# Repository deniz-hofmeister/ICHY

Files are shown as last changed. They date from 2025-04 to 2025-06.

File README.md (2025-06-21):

# ICHY - 8-Element Microphone Phased Array

## Project Overview
ICHY is a 8-element microphone phased array designed for high-precision audio source localization and beamforming. This document outlines the key design considerations, components, and implementation approach.

## Key Design Elements

### Hardware
- **Microphones**: 8 MEMS microphones with matched frequency response
- **Geometry**: Square array of 4x4 microphones
- **Spacing**: λ/2 spacing to prevent spatial aliasing at target frequencies
- **ADC**: Simultaneous sampling across all channels

### Signal Processing
- **Beamforming Algorithm**: Delay-and-sum with optional adaptive algorithms
- **Calibration**: Inter-microphone calibration methodology
- **Filtering**: Band-pass filtering to focus on frequencies of interest
- **Direction Finding**: MUSIC or SRP-PHAT algorithm implementation

### Software
- **DSP Pipeline**: Real-time processing chain
- **Visualization**: Direction-of-arrival display
- **Interface**: Configuration and monitoring interface
- **Data Storage**: Recording capabilities for post-processing

### Performance Targets
- **Angular Resolution**: <5° at target frequency range
- **Frequency Range**: 1kHz - 8kHz optimal operation
- **Processing Latency**: <50ms for real-time applications

## Data Acquisition Architecture

### Minimal Hardware Configuration for Jetson Processing

#### Essential Hardware Components
- **Microphones**: 8 digital MEMS microphones (I2S/PDM output)
- **Clock Source**: Single master clock with distribution network to ensure phase alignment
- **Audio Codec/Interface**: Audio interface with multi-channel input capabilities
- **Physical Array Structure**: Precise physical positioning framework for microphones
- **Power Conditioning**: Clean power supply with proper isolation

#### Non-Replaceable Hardware Elements
1. **Microphone Transducers**: Physical conversion of sound to electrical signals cannot be done in software
2. **Clock Synchronization Hardware**: Physical timing alignment between microphones (~1μs precision)
3. **Physical Array Geometry**: Precise spatial positioning that affects beamforming accuracy
4. **Signal Conditioning**: Analog filters and buffers to maintain signal integrity
5. **ADC Hardware**: Conversion from analog to digital (integrated in digital MEMS mics)

### Jetson-Based Processing Approach
- **Direct Interfaces**: Utilize Jetson's I2S/SPI interfaces for direct microphone connection where possible
- **Audio Interface Options**:
  1. Direct connection of PDM microphones to Jetson's hardware interfaces
  2. Multi-channel audio codec with TDM output connected to Jetson
  3. USB audio interface with multi-channel capability

### Software-Replaceable Components
- **Digital Filtering**: All filtering can be performed in software on Jetson
- **Beamforming Algorithms**: Implemented entirely in CUDA on Jetson GPU
- **Signal Conditioning**: Digital gain, normalization in software
- **Channel Synchronization**: Fine synchronization adjustments in software
- **Calibration**: Software-based microphone calibration routines
- **Direction Finding**: All direction finding algorithms in CUDA

### Jetson Processing Implementation
- **Nvidia Jetson Advantages**:
  1. **Integrated Solution**: ARM CPU cores + CUDA-capable GPU on single board
  2. **Direct I/O**: Hardware interfaces for connecting to microphone array
  3. **Unified Memory**: Shared memory architecture for efficient CPU-GPU data exchange
  4. **Complete Software Stack**: CUDA libraries for signal processing optimization
  
- **Jetson Signal Processing Pipeline**:
  1. **Data Acquisition**: 
     - Direct digital sampling from microphones via I2S/PDM interfaces
     - DMA transfer to Jetson memory with minimal CPU involvement
  
  2. **Pre-Processing on CPU**:
     - Initial buffering and sample rate conversion if needed
     - Channel synchronization fine-tuning
     - Data preparation for GPU processing
  
  3. **GPU Processing with CUDA**:
     - Batch processing of multi-channel audio data
     - FFT-based operations across all channels in parallel
     - Beamforming coefficients calculation
     - Direction-of-arrival estimation using MUSIC/SRP-PHAT
  
  4. **Real-time Visualization and Output**:
     - Direction finding results visualization
     - Beamformed audio output
     - Optional raw data storage for post-processing

- **Optimized Jetson Implementation**:
  - Use of Jetson-specific optimizations (cuDNN, TensorRT if applicable)
  - Zero-copy memory operations between CPU and GPU when possible
  - Asynchronous processing to maintain real-time performance
  - GPU kernel fusion to minimize data movement

### Power and Thermal Considerations
- **Power Distribution**: Clean, low-noise power supply to each microphone
- **Isolation**: Digital/analog domain isolation to prevent noise coupling
- **Thermal Design**: Heat dissipation strategy for continuous operation

## Design Artifacts

### PCB Design
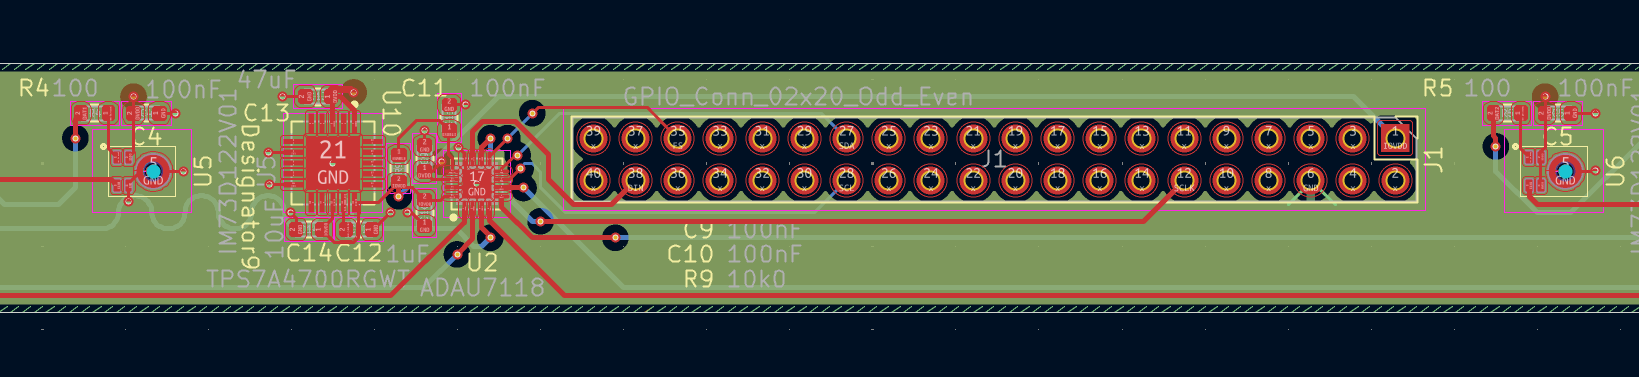
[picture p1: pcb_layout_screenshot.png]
PCB Layout Screenshot


### Schematic
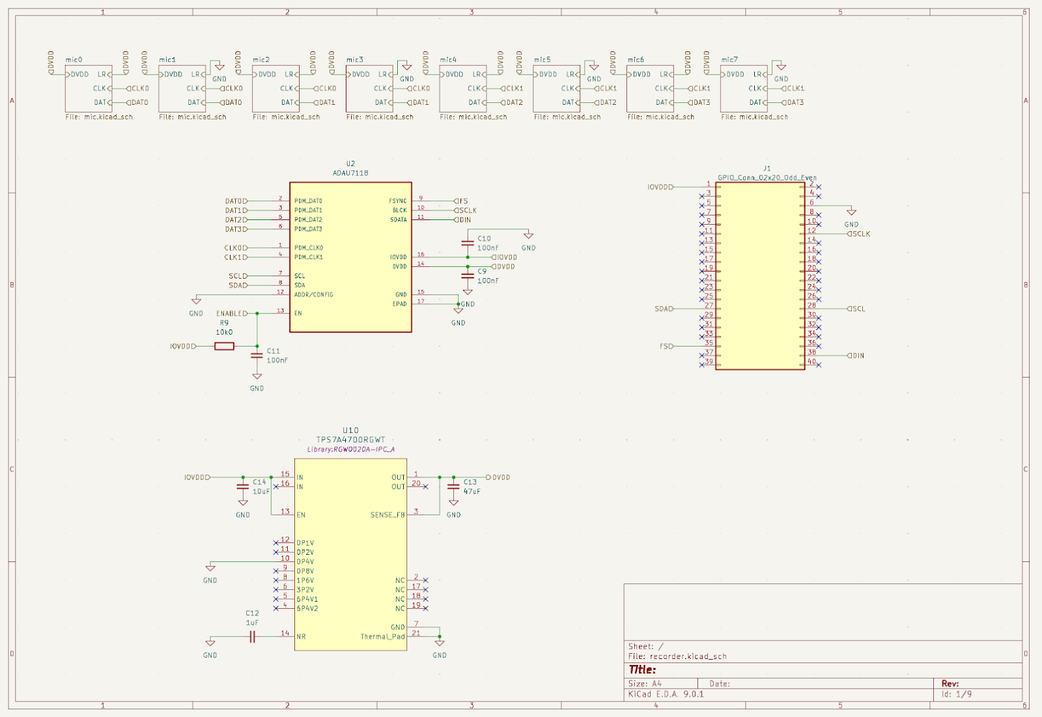
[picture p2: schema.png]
Schema Diagram


### 3D View
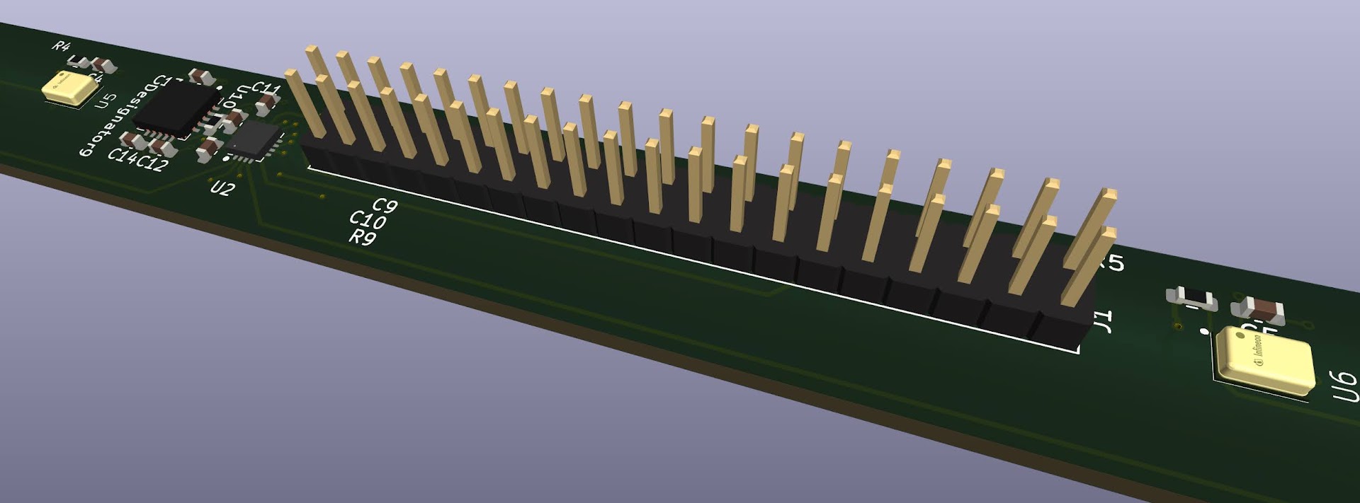
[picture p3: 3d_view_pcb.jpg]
3D View of PCB


### Left side of the PCB, right is mirrored
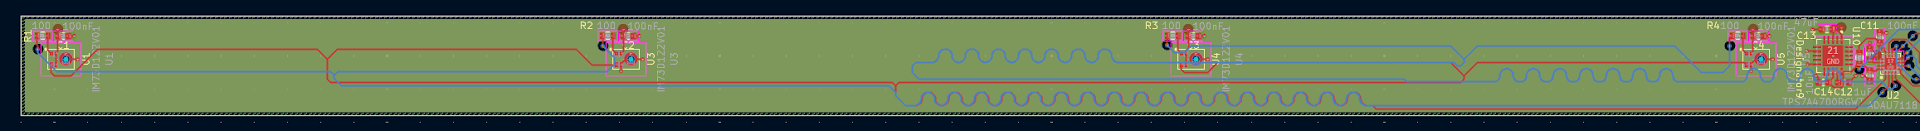
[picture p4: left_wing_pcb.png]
Left side PCB


## Next Steps
- Detailed microphone selection and array geometry calculation
- Electronics design and component selection
- DSP algorithm implementation
- Mechanical design and housing
- Software development and user interface
- Testing and calibration methodology

## References
- Key academic papers and resources for phased array design
- Component datasheets and reference implementations

## Developer Guide
- https://docs.nvidia.com/jetson/archives/r36.4/DeveloperGuide/SD/Communications/AudioSetupAndDevelopment.html

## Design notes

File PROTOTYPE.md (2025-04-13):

# Design Document: 8-Microphone Array Prototype

This document details the design and implementation plan for a simple 8-microphone digital array prototype. The prototype is aimed at validating beamforming and audio processing algorithms on an embedded platform (such as an NVIDIA Jetson). The design focuses on minimized complexity by using a single ADAU7118 PDM-to-TDM converter with its internal clock generation, eliminating the need for an external clock distribution network.

---

## 1. Overview

The 8-microphone prototype leverages digital MEMS microphones (Infineon IM73D122) and one ADAU7118 converter to digitize the microphone signals and output a synchronized TDM/I²S stream. By limiting the system to one converter and eight elements, we simplify PCB layout, reduce calibration challenges, and streamline the development of DSP routines.

---

## 2. System Architecture

### 2.1 Block Diagram

```
  +---------------------+
  | 8 MEMS Microphones  |   <-- Arranged in a 2D configuration (e.g., linear or square array)
  +---------------------+
            |
            v
  +---------------------+
  |  ADI ADAU7118       |   <-- 8-channel PDM-to-TDM converter with internal clock generation
  +---------------------+
            |
            v
  +---------------------+
  |   Power Supply      |   <-- Low-noise regulators and decoupling circuits
  +---------------------+
            |
            v
  +---------------------+
  |   NVIDIA Jetson     |   <-- Host processor for real-time DSP and beamforming
  | (I²S/TDM & I²C Bus)  |
  +---------------------+
```

### 2.2 Signal Flow

1. **Acoustic Signal Capture:**  
   Each Infineon IM73D122 microphone converts sound into a digital PDM bitstream.

2. **Digital Conversion:**  
   The ADAU7118 accepts all 8 PDM inputs, converts them into a coherent digital audio stream (TDM/I²S) using its internally generated clock, and applies initial filtering and gain adjustments.

3. **Data Acquisition:**  
   The digitized audio stream is transmitted via the TDM/I²S interface to the NVIDIA Jetson board, where further processing, including beamforming and direction finding, is performed.

4. **Configuration:**  
   An I²C control bus configures and monitors the ADAU7118 settings such as clock parameters, TDM slot assignments, and filtering options.

---

## 3. Hardware Components

### 3.1 MEMS Microphones

- **Model:** Infineon IM73D122  
- **Key Specifications:**
  - Digital PDM interface
  - Ultra-high SNR (73 dB(A))
  - Sensitivity: -26 dBFS
  - Low Frequency Roll-Off (LFRO): 20 Hz

**Considerations & Pitfalls:**
- **Array Layout:**  
  • Establish proper physical spacing as needed (e.g., λ/2 for the target frequency range) to avoid spatial aliasing.
- **Signal Integrity:**  
  • Ensure equal trace lengths for all PDM signal lines to minimize timing skew.
- **Environmental Factors:**  
  • Guard against EMI and mechanical stress which could affect the microphones’ precision.

### 3.2 ADAU7118 PDM-to-TDM Converter

- **Role:**  
  Converts the 8 PDM inputs into a synchronized, digital TDM/I²S stream and manages the necessary filtering.  
- **Key Features:**
  - Internal, automatic PDM clock generation—removing the need for an external clock circuit.
  - Dual PDM clock outputs to drive the connected microphones.
  - Configurable TDM slot routing.

**Considerations & Pitfalls:**
- **Internal Clocking:**  
  • Rely on the ADAU7118’s built-in clock generator to simplify design.
  • Ensure proper configuration during initialization via the I²C interface.
- **I²C Communication:**  
  • Utilize correct pull-up resistors on SDA and SCL lines.
  • Keep I²C wiring short to minimize noise and ensure robust communication.

### 3.3 Power Supply and Regulation

- **Requirements:**  
  • Deliver low-noise and well-regulated voltages to all active components.  
  • Separate regulation may be required for digital (IOVDD) and analog (DVDD) parts of the ADAU7118.
  
**Considerations & Pitfalls:**
- **Decoupling:**  
  • Place decoupling capacitors immediately adjacent to power pins of the ADAU7118 and microphones.
  • Ensure proper bypassing to reduce ripple and noise.
- **Isolation:**  
  • Maintain isolation between analog and digital supplies to reduce interference.
- **Power Sequencing:**  
  • Implement proper sequencing to avoid latch-ups or unstable startup conditions.

### 3.4 Interface to NVIDIA Jetson

- **Primary Interfaces:**
  - **TDM/I²S Data Bus:** Transmits the audio stream from the ADAU7118 to the Jetson.
  - **I²C Bus:** Enables configuration and status monitoring of the ADAU7118.

**Considerations & Pitfalls:**
- **Voltage Levels:**  
  • Check and match voltage levels between the ADAU7118 and the Jetson board.
  • Use level shifters if necessary.
- **Signal Integrity:**  
  • Adhere to I²S/TDM timing requirements to ensure correct data capture.
  • Design PCB traces to minimize EMI and crosstalk.
- **Connector Quality:**  
  • Use robust connectors and test points, especially for debugging during prototype development.

---

## 4. PCB Layout Considerations

### 4.1 Routing

- **Critical Signal Traces:**
  - **PDM Data & Clock Lines:**  
    • Route with identical lengths and smooth curves to avoid geometry-induced skew.
  - **I²S/TDM and I²C Lines:**  
    • Keep these traces short and, if possible, use controlled impedance lines.

**Pitfalls:**
- Non-uniform trace lengths can result in phase misalignment.
- Improper impedance control may cause reflections and data errors.

### 4.2 Grounding

- **Ground Planes:**  
  • Provide solid ground planes for both analog and digital sections and connect them at a single common point to prevent ground loops.
  
**Pitfalls:**
- Shared or noisy ground planes can couple interference into sensitive analog signal paths.
- Inadequate decoupling between ground planes can degrade signal integrity.

### 4.3 Component Placement

- **Proximity:**  
  • Position the ADAU7118 as close to the microphone array as possible to minimize PDM trace lengths.
  - Position power management components near main supply input for effective decoupling.
  
**Pitfalls:**
- Overcrowded areas can lead to thermal issues and increased EMI.
- Improper layout might cause cross-talk between sensitive signals.

---

## 5. Firmware and Software Considerations

### 5.1 ADAU7118 Configuration

- **I²C Initialization:**  
  • Write routines to set up the internal clock, configure TDM slot routing, and apply filter parameters.
- **Error Handling:**  
  • Implement robust error-handling and retries to manage potential I²C communication issues.

### 5.2 Data Acquisition

- **I²S/TDM Data Handling:**  
  • Develop firmware on the Jetson side to reliably capture and process the audio stream.
- **Buffer Management:**  
  • Ensure sufficient buffering to maintain a continuous and real-time data stream.

### 5.3 Testing and Debugging

- **Signal Monitoring:**  
  • Use oscilloscopes and logic analyzers to verify the integrity of PDM clocks, I²S/TDM data, and I²C transactions.
- **Calibration Routines:**  
  • Develop software calibration routines to align the gain and phase across the 8 microphones.
- **Logging:**  
  • Implement thorough logging to aid in identifying issues related to signal integrity or communication.

**Pitfalls:**
- Software latency or jitter may affect real-time processing; ensure optimization of data handling routines.
- Insufficient error logging may hinder the debugging process.

---

## 6. Testing, Calibration, and Potential Pitfalls

### 6.1 Testing Steps

1. **Power Supply Verification:**  
   - Confirm voltage levels, low noise, and effective decoupling.
2. **Internal Clock Verification:**  
   - Validate the performance of the ADAU7118’s internal clock using measurement tools.
3. **Data Stream Integrity:**  
   - Use test patterns to ensure the TDM/I²S data stream is correct before processing real audio data.
4. **I²C Communication Testing:**  
   - Verify proper register configuration and stable communication with the ADAU7118.
5. **Full Audio System Testing:**  
   - Conduct beamforming tests with controlled sound sources to ensure the system’s performance.

### 6.2 Calibration and Tuning

- **Microphone Equalization:**  
  • Calibrate each microphone to correct sensitivity variations.
- **Phase Alignment:**  
  • Ensure phase alignment is achieved to support accurate beamforming.
- **DSP Tuning:**  
  • Adjust gain, filtering, and beamforming coefficients based on practical acoustic data.

### 6.3 Key Pitfalls and Mitigations

- **Clock Integrity Issues:**  
  • Relying solely on the ADAU7118’s internal clock simplifies design but still requires validation to ensure low jitter.
- **Power Supply Noise:**  
  • Use adequate decoupling and filtering to prevent noise that could degrade audio quality.
- **Crosstalk and EMI:**  
  • Follow strict PCB layout rules, maintain separation between signal lines, and provide robust grounding.
- **I²C Communication Errors:**  
  • Validate proper pull-up resistor values and ensure short, shielded wiring for the I²C bus.
- **Software Latency:**  
  • Optimize firmware to support real-time audio processing and mitigate any buffering issues.

---

## 7. Conclusion

This 8-microphone prototype is designed to provide a straightforward and effective platform for validating critical DSP and beamforming functionalities. By leveraging a single ADAU7118 for both conversion and internal clock generation, the design minimizes complexity while maintaining performance accuracy. The detailed attention to power, signal integrity, and firmware reliability ensures that the prototype is robust and scalable for future enhancements, eventually paving the way to expand this design to larger arrays.

---

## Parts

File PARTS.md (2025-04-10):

# ICHY - Component Selection

## Microphone Selection

### Selected Model: Infineon IM73D122
- **Interface**: PDM (Pulse Density Modulation)
- **Package Size**: 4.00 x 3.00 x 1.20 mm
- **SNR**: 73 dB(A) - Ultra-high SNR
- **AOP (Acoustic Overload Point)**: 120/122 dBSPL (1%/10% THD)
- **Current Consumption**: 980 μA @ 3.072 MHz
- **Sensitivity**: -26 dBFS
- **LFRO (Low Frequency Roll-Off)**: 20 Hz
- **Key Features**: Ultra-high SNR & sensitivity

### Selection Rationale
The IM73D122 was selected for the 16-element microphone array due to:
- **Ultra-high SNR**: Provides cleanest signal for precise beamforming and direction finding
- **High Sensitivity**: Optimal for capturing distant sound sources
- **PDM Interface**: Compatible with Jetson platform's digital interfaces
- **Low Frequency Response**: 20Hz roll-off extends well below our 1kHz-8kHz target range
- **Uniform Characteristics**: Infineon MEMS microphones offer matched frequency response required for phased array applications

### Alternative Models Considered

| Model | Main Features | Interface | Package Size [mm] | SNR | AOP (1/10%THD) | Current | Sensitivity | LFRO [Hz] |
|---|---|---|---|-----|---|---|---|---|
| IM69D130 | High SNR and high AOP | PDM | 4.00 x 3.00 x 1.20 | 69 dB(A) | 128/130 dBSPL | 980 μA @ 3.072 MHz | -36 dBFS | 28 |
| IM69D120 | High SNR and sensitivity | PDM | 4.00 x 3.00 x 1.20 | 69 dB(A) | 118/120 dBSPL | 980 μA @ 3.072 MHz | -26 dBFS | 28 |
| IM69D127 | High performance in small size | PDM | 3.60 x 2.50 x 1.00 | 69 dB(A) | 123/127 dBSPL | 980 μA @ 3.072 MHz | -34 dBFS | 40 |
| IM69D128S | Ultra-low current consumption | PDM | 3.50 x 2.65 x 1.00 | 69 dB(A) | 125/128 dBSPL | 520 μA @ 3.072 MHz | -37 dBFS | 30 |
| IM70D122 | High SNR and sensitivity | PDM | 3.50 x 2.65 x 1.00 | 70 dB(A) | 120/122 dBSPL | 980 μA @ 3.072 MHz | -26 dBFS | 30 |
| IM72D128 | Ultra-high SNR | PDM | 4.00 x 3.00 x 1.20 | 72 dB(A) | 126/128 dBSPL | 980 μA @ 3.072 MHz | -36 dBFS | 20 |
| IM73D122 | Ultra-high SNR & sensitivity | PDM | 4.00 x 3.00 x 1.20 | 73 dB(A) | 120/122 dBSPL | 980 μA @ 3.072 MHz | -26 dBFS | 20 |

## Data Acquisition & Processing Components

### PDM to TDM Conversion Options

#### Option 1: Texas Instruments PCMD3180/PCMD3180-Q1
- **Description**: 8-Channel Audio Analog-to-Digital Converter (PDM to TDM/I2S)
- **Channels**: 8 PDM microphones simultaneous conversion
- **Output Format**: TDM, I2S, or left-justified (LJ) formats (compatible with Jetson platform)
- **Sampling Rate**: 8kHz to 768kHz programmable output sample rate
- **Package Size**: 24-pin WQFN package
- **Power Consumption**: 2.5mW/channel at 48kHz sample rate (1.8V supply)
- **Special Features**: 127dB dynamic range, programmable digital volume control, microphone bias voltage, phase-locked loop (PLL), programmable high-pass filter, bi-quad filters, low-latency filter modes
- **Temperature Range**: –40°C to +125°C
- **Supplier Link**: https://www.mouser.co.uk/new/texas-instruments/ti-pcmd3180-audio-adc/

#### Option 2: Analog Devices ADAU7118
- **Description**: 8-Channel PDM to TDM/I2S audio converter
- **Channels**: 8 PDM microphones (4 stereo pairs)
- **Output Format**: I2S or TDM (up to TDM-16) compatible with Jetson platform
- **Sampling Rate**: 4kHz to 192kHz output sampling rate
- **Package Size**: 16-lead, 3mm × 3mm, 0.50mm pitch LFCSP
- **Power Consumption**: 1.2mA operating current for 8 channels at 48kHz (1.8V supply)
- **Special Features**: 126dB A-weighted SNR, 24-bit resolution, selectable I2C control, configurable TDM slot routing, dual PDM clock outputs, automatic PDM clock generation
- **Temperature Range**: -40°C to +85°C
- **Supply Voltage**: I/O (1.70V to 3.63V), DVDD (1.10V to 1.98V)
- **Supplier Link**: https://www.mouser.co.uk/new/analog-devices/adi-adau7118-converter/

#### Option 3: Tempo Semiconductor TSDP18xx
- **Description**: Octal PDM to TDM/I2S converter (8-Channel DMIC Aggregator)
- **Channels**: 8 PDM microphones
- **Output Format**: I2S (1 or 2 channels), Left-Justified (1 or 2 channels), or TDM (1-8 channels)
- **Sampling Rate**: 8kHz to 384kHz output sampling rate
- **Resolution**: 16-bit or 24-bit Linear PCM
- **Power Consumption**: Ultra-low power (<1μA in standby)
- **Special Features**: >142dB SNR, 6th order 24-bit filtering, flexible oversampling options (32x to 512x), supports SCLK polarity inversion, configurable FRMCLK widths
- **Supply Voltage**: IOVDD (1.8V or 3.3V), DVDD (1.8V)
- **Supplier Link**: https://temposemi.com/wp-content/uploads/2019/09/TSDP18xx_DS.pdf

#### Comparison Table

| Feature | TI PCMD3180 | ADI ADAU7118 | Tempo TSDP18xx |
|---|---|---|---|
| Channels | 8 PDM microphones | 8 PDM microphones (4 stereo pairs) | 8 PDM microphones |
| Sampling Rates | 8kHz to 768kHz | 4kHz to 192kHz | 8kHz to 384kHz |
| Resolution | N/A | 24-bit | 16-bit or 24-bit |
| Package Size | 24-pin WQFN | 16-lead, 3mm × 3mm LFCSP | N/A |
| Power | 2.5mW/channel @ 48kHz | 1.2mA total @ 48kHz (1.8V) | <1μA standby |
| SNR | 127dB dynamic range | 126dB A-weighted SNR | >142dB |
| Temperature Range | -40°C to +125°C | -40°C to +85°C | N/A |
| Output Formats | TDM, I2S, LJ | I2S or TDM (up to TDM-16) | I2S, LJ, TDM (1-8 channels) |
| Key Advantage | Highest sampling rate, wider temp range | Lower power, smaller package | Highest SNR, ultra-low power |
| Special Features | HPF, bi-quad filters | Dual PDM clocks | 6th order filtering, flexible oversampling |

### PDM to TDM Converter Selection Analysis

After evaluating all three options, we've carefully considered the requirements for connecting 16 Infineon IM73D122 PDM microphones to an NVIDIA Jetson platform. Since each converter chip can handle 8 PDM inputs, two chips will be required regardless of which solution is chosen.

#### TI PCMD3180 Analysis
**Pros:**
- Highest maximum sampling rate (768kHz) providing significant headroom
- Wide temperature range (-40°C to +125°C) for operation in varied environments
- 127dB dynamic range, well above the microphones' 73dB SNR
- Comprehensive filtering options (HPF, bi-quad filters)

**Cons:**
- Higher power consumption (2.5mW/channel)
- Larger package size (24-pin WQFN)
- More complex implementation compared to alternatives

#### ADI ADAU7118 Analysis
**Pros:**
- Lowest specified active power consumption (1.2mA total for 8 channels)
- Smallest package size (3mm × 3mm LFCSP) optimizing PCB space
- Automatic PDM clock generation simplifies design
- Dual PDM clock outputs beneficial for synchronization
- TDM-16 support enables efficient interface to the Jetson platform
- 126dB SNR exceeds microphone specifications by a wide margin

**Cons:**
- Lower maximum sampling rate than alternatives (though 192kHz is still more than adequate)
- Narrower temperature range than the TI option (-40°C to +85°C)

#### Tempo TSDP18xx Analysis
**Pros:**
- Highest SNR (>142dB) of all options
- Excellent standby power consumption (<1μA)
- Flexible oversampling options (32x to 512x)
- 6th order 24-bit filtering

**Cons:**
- Active power consumption not clearly specified
- Package size not specified
- Less detailed documentation available compared to TI and ADI offerings

#### Integration Complexity Analysis

Since design simplicity and reliability are critical factors for this 16-element microphone array, we've performed a detailed analysis of each option's integration complexity:

##### ADI ADAU7118 Integration Advantages
1. **Clock Management Simplicity**
   - Automatic PDM clock generation eliminates need for external clock circuitry
   - Dual PDM clock outputs provide synchronized clocking across all 16 microphones
   - Reduces timing error risks in the microphone array that could affect beamforming accuracy

2. **Streamlined Data Routing**
   - TDM-16 support allows outputs from both converter chips to be combined into a single data stream
   - Configurable TDM slot routing provides flexibility in channel assignment
   - Single synchronized interface to Jetson simplifies firmware and driver development
   - Reduces the number of required data lines between converters and Jetson

3. **PCB Layout Efficiency**
   - 3mm × 3mm package enables more compact array design with shorter signal paths
   - Smaller footprint simplifies PCB routing and reduces layer requirements
   - Potentially reduces crosstalk and interference between channels

4. **Configuration Interface**
   - Standardized I2C control interface is well-supported on Jetson platforms
   - Automatic features reduce required configuration parameters
   - Well-documented specifications simplify integration

##### TI PCMD3180 Integration Challenges
1. **Clock Management Complexity**
   - PLL present but lacks automatic PDM clock generation
   - May require additional external timing components
   - More configuration parameters for clock setup

2. **PCB Design Complexity**
   - 24-pin WQFN package demands significantly more board space
   - More complex signal routing with larger package
   - Potentially requires additional PCB layers for routing

3. **Feature Overhead**
   - Comprehensive filtering options require more configuration programming
   - Higher sampling capabilities add configuration complexity
   - May require more complex initialization sequences

##### Tempo TSDP18xx Integration Limitations
1. **Documentation Gaps**
   - Less detailed documentation increases implementation risks
   - May require more engineering time for testing and validation
   - Higher potential for integration issues without comprehensive documentation

2. **Interface Limitations**
   - TDM support limited to 8 channels vs ADAU7118's 16 channels
   - Likely requires more complex routing between converter chips and Jetson
   - May require additional interface configuration

3. **Physical Implementation Uncertainties**
   - Unspecified package size creates layout uncertainty
   - Integration complexity difficult to fully assess without complete specifications

#### Final Selection: ADI ADAU7118

We have selected the ADI ADAU7118 as the optimal PDM to TDM converter for this application for the following reasons:

1. **Integration Simplicity**: The ADAU7118 provides the most straightforward implementation path with automatic clock generation, dual PDM clock outputs, and TDM-16 support that simplifies the interface to the Jetson platform. This reduces development time and potential for integration issues.

2. **Compact Design**: The smallest package size (3mm × 3mm) enables a more compact microphone array design with simpler PCB layout.

3. **Adequate Performance**: The 126dB SNR and 192kHz maximum sampling rate significantly exceed our requirements for the 1kHz-8kHz target frequency range.

4. **Power Efficiency**: The ADAU7118 provides the lowest specified active power consumption, which is beneficial for a 16-element array that requires two converter chips.

5. **Well-Documented Solution**: Comprehensive documentation reduces implementation risks and provides clear integration paths.

While the TSDP18xx offers superior SNR and the PCMD3180 provides higher maximum sampling rates and wider temperature range, these advantages aren't necessary given the microphones' specifications and the project's target frequency range. The ADAU7118 provides the optimal balance of integration simplicity, form factor, and performance for this application, potentially reducing development time and reliability risks compared to alternatives.

### Clock Distribution
- TBD: Precision clock distribution network for synchronizing all 16 microphones

### Audio Interface
- TBD: Multi-channel PDM interface compatible with Jetson platform

### Computing Platform
- **Selected Platform**: NVIDIA Jetson (specific model to be determined)
- **Rationale**: Integrated ARM CPU + CUDA-capable GPU for real-time audio processing and beamforming

## Additional Resources
- [Infineon XENSIV™ Sensor Solutions Catalog 2024](https://www.infineon.com/dgdl/Infineon-xensiv_sensor_solutions_2024-ProductSelectionGuide-v01_00-EN.pdf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)
- [IM73D122 Datasheet](https://www.infineon.com/cms/en/product/sensor/mems-microphones/mems-microphones-for-consumer/im73d122/)

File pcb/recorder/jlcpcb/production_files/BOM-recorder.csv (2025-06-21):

Comment | Designator | Footprint | LCSC | Quantity
1uF | C12 | C_0603_1608Metric | C105524 | 1
220nF | C1,C10,C11,C2,C3,C4,C5,C6,C7,C8,C9 | C_0603_1608Metric | C106250 | 11
4700nF | C13 | C_0603_1608Metric | C107368 | 1
100 | R1,R2,R3,R4,R5,R6,R7,R8 | R_0603_1608Metric | C22775 | 8
22 | R12,R13,R14 | R_0603_1608Metric | C23345 | 3
10000 | R9 | R_0603_1608Metric | C25804 | 1
TPS7A4700RGWT | U10 | RGW0020A-IPC_A | C28286 | 1
10uF | C14 | C_0603_1608Metric | C3039698 | 1
GPIO_Conn_02x20_Odd_Even |  | PinHeader_2x20_P2.54mm_Vertical | C5224014 | 0
IM73D122V01 | U1,U3,U4,U5,U6,U7,U8,U9 | IM73D122V01 | C5563886 | 8
ADAU7118 | U2 | LFCSP-16 | C654437 | 1

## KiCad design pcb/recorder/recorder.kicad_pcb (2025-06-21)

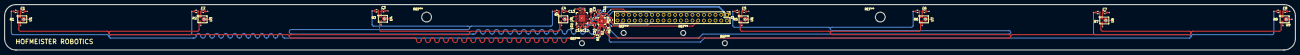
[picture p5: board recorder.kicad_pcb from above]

Board: 4 copper layers, 569.0 x 20.0 mm, 37 parts (0 on the bottom side), 27 nets.

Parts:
C1, C2, C3, C4, C5, C6, C7, C8, C9, C10, C11: 220nF; C_0603_1608Metric
C12: 1uF; C_0603_1608Metric
C13: 4700nF; C_0603_1608Metric
C14: 10uF; C_0603_1608Metric
J1: GPIO_Conn_02x20_Odd_Even; PinHeader_2x20_P2.54mm_Vertical
R1, R2, R3, R4, R5, R6, R7, R8: 100; R_0603_1608Metric
R9: 10000; R_0603_1608Metric
R12, R13, R14: 22; R_0603_1608Metric
U1, U3, U4, U5, U6, U7, U8, U9: IM73D122V01
U2: ADAU7118; LFCSP-16
U10: TPS7A4700RGWT; RGW0020A-IPC_A

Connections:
/CLK0: R12.2, U1.3 (CLOCK), U3.3 (CLOCK), U4.3 (CLOCK), U5.3 (CLOCK)
/CLK1: R13.2, U6.3 (CLOCK), U7.3 (CLOCK), U8.3 (CLOCK), U9.3 (CLOCK)
/DAT0: R1.2, R2.2, U2.2 (PDM_DAT0)
/DAT1: R3.2, R4.2, U2.3 (PDM_DAT1)
/DAT2: R5.2, R6.2, U2.5 (PDM_DAT2)
/DAT3: R7.2, R8.2, U2.6 (PDM_DAT3)
/DIN: J1.38 (I2S0_DIN), R14.1
/DVDD: C1.1, C2.1, C3.1, C4.1, C5.1, C6.1, C7.1, C8.1, C9.1, C13.1, U1.2 (VDD), U1.4 (LR), U2.14 (DVDD), U3.2 (VDD), U4.2 (VDD), U4.4 (LR), U5.2 (VDD), U6.2 (VDD), U6.4 (LR), U7.2 (VDD), U8.2 (VDD), U8.4 (LR), U9.2 (VDD), U10.1 (OUT), U10.3 (SENSE_FB)
/ENABLE: C11.1, R9.1, U2.13 (EN)
/FS: J1.35 (I2S0_FS), U2.9 (FSYNC)
/IOVDD: C10.1, C14.1, J1.1 (3V3), R9.2, U2.16 (IOVDD), U10.13 (EN), U10.15 (IN)
/SCL: J1.28 (I2C0_SCL), U2.7 (SCL)
/SCLK: J1.12 (I2S0_SCLK), U2.10 (BLCK)
/SDA: J1.27 (I2C0_SDA), U2.8 (SDA)
GND: C1.2, C2.2, C3.2, C4.2, C5.2, C6.2, C7.2, C8.2, C9.2, C10.2, C11.2, C12.2, C13.2, C14.2, J1.6 (GND), U1.5 (GND), U2.12 (ADDR/CONFIG), U2.15 (GND), U2.17 (EPAD), U3.4 (LR), U3.5 (GND), U4.5 (GND), U5.4 (LR), U5.5 (GND), U6.5 (GND), U7.4 (LR), U7.5 (GND), U8.5 (GND), U9.4 (LR), U9.5 (GND), U10.7 (GND), U10.10 (0P4V), U10.21 (Thermal_Pad)
unnamed: R1.1, U1.1 (DATA)
unnamed: R12.1, U2.1 (PDM_CLK0)
unnamed: R13.1, U2.4 (PDM_CLK1)
unnamed: R14.2, U2.11 (SDATA)
unnamed: R2.1, U3.1 (DATA)
unnamed: R3.1, U4.1 (DATA)
unnamed: R4.1, U5.1 (DATA)
unnamed: R5.1, U6.1 (DATA)
unnamed: R6.1, U7.1 (DATA)
unnamed: R7.1, U8.1 (DATA)
unnamed: R8.1, U9.1 (DATA)
unnamed: C12.1, U10.14 (NR)

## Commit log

2025-04-13 Prototype v1 Target
2025-04-19 kicad imports not functional yet
    [main.kicad_pcb, main.kicad_sch]
2025-04-23 Add initial PCB design.
    [main.kicad_pcb, main.kicad_sch]
2025-04-23 Update scaling of molex connector to convert from mm to inch :(
    [main.kicad_pcb]
2025-06-21 changed design to single-row, no connectors
    [BOM-recorder.csv, main.kicad_pcb, main.kicad_sch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]
2025-06-21 another pcb view
2025-06-21 shrunk pcb
    [recorder.kicad_pcb]
2025-06-21 clock traces redone
    [recorder.kicad_pcb]
2025-06-21 traces redone, DATA and CLK matched
    [recorder.kicad_pcb]
2025-06-21 DRC updates
    [recorder.kicad_pcb]
2025-06-21 shrunk to 569 mm
    [recorder.kicad_pcb]
